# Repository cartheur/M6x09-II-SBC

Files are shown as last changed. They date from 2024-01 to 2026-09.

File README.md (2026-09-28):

## M6x09-II-SBC

A minature seventeen-component singleboard computer to experiment with the `x09` architecture. The sister repository can be found [here](https://github.com/cartheur/M6x09-A).

The Linux terminal application for connecting to this board via FTDI is documented [here](terminal/README.md).

### Working Readmes

For the active Linux-side workflow, start here:

- [Linux terminal bring-up](terminal/README.md)
- [ROM build and Batronix Barlino II 32P burn flow](roms/README.md)
- [ASSIST09 source tree](src/README.md)

The current ROM monitor source is [ASSIST09 source](src/assist-09/assist09.asm).

_Preface_

So often, engineers go crazy on adding features to create the perfect singleboard computer. In the 8-bit world, it is really most interesting to get to the nut of the matter: Can we create the simplest hardware system to test those things we are building-out, such as the bits of a novel kernel or memory management, or evolution to multiprocessing?

This project is what we can discern is the _minimal_ system using modern connetions to a laptop running debian where we can get to understanding how the _ideal_ is in terms of _novel metal_.

_Insistences_

The ideal project should NOT be exploited into higher monetary platitudes simply because people love it. Rather, what open-source tools are the most trustworthy (free of manipulation by intellectual corruption) that will have any engineer who replicates this project have the same success in whatever the future time may be?

_The board_

Layout (v1.1)

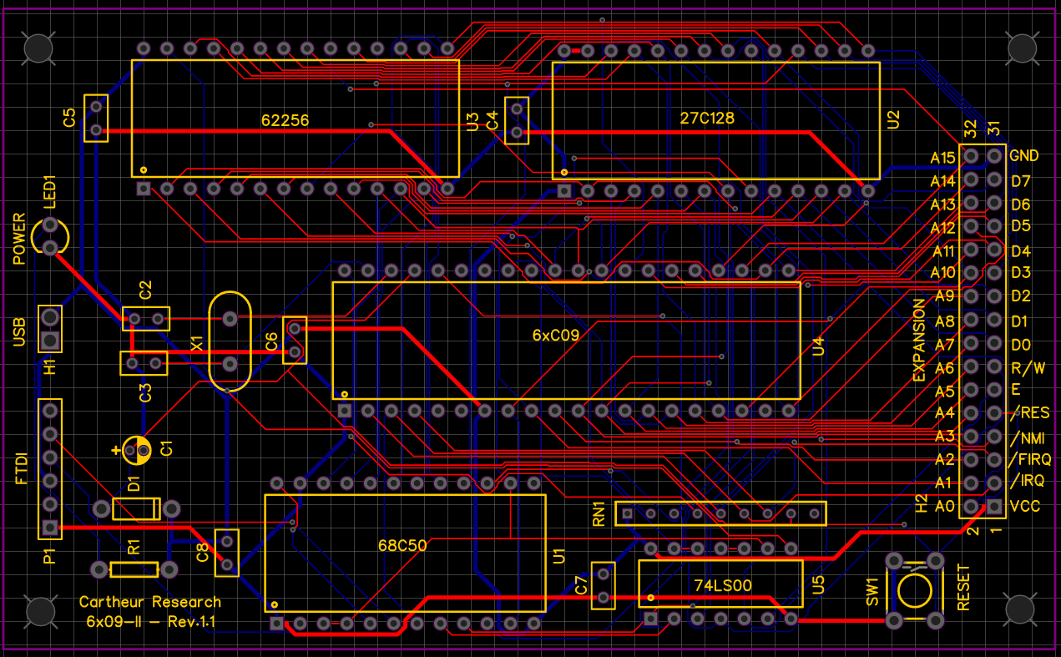
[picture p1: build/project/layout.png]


The manufactured ouput (unassembled version).

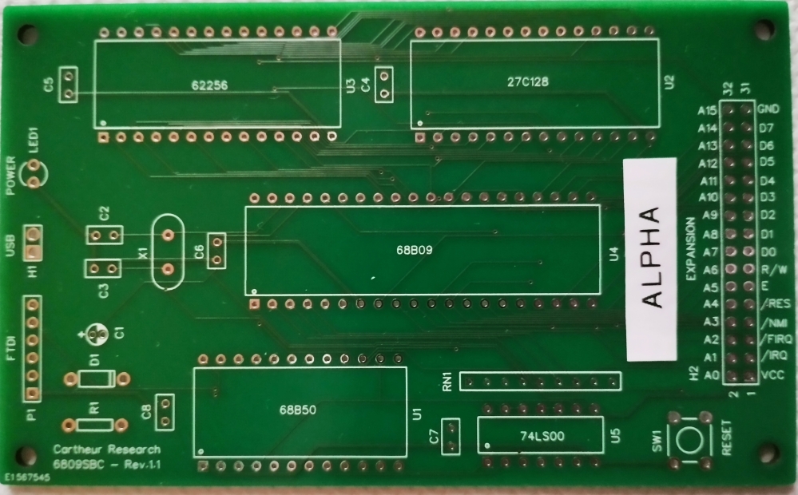
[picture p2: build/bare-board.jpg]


_Parts list_

| ID | Name | Designator | Footprint | Quantity | Part Number | Manufacturer | Supplier | Supplier Part Number | Unit Price (EUR) |
| --- | --- | --- | --- | --- | --- | --- | --- | --- | --- |
| 1 | 10uF | C1 | CAP-D3.0XF1.5 | 1 | ECA-1VM100 | Panasonic | Mouser | 667-ECA-1VM100 | 0.167 |
| 2 | 18pF | C2-C3 | RAD-0.1 | 2 | K180J15C0GF5TL2 | Vishay | Mouser | 594-K180J15C0GF5TL2 | 0.214 |
| 3 | 0.1uF | C4-C5-C6-C7-C8 | RAD-0.1 | 5 | K104K15X7RH53H5G | Vishay | Mouser | 594-K104K15X7RH53H5G | 0.698 |
| 4 | 1N914 | D1 | DO-35 | 1 | 1N914 | Fairchild | Mouser | 512-1N914 | 0.093 |
| 5 | USB POWER JUMPER | H1 | HDR-2X1/2.54 | 1 | 826629-2 | TE Connectivity | Mouser | 571-826629-2 | 0.316 |
| 6 | EXPANSION HEADER | H2 | HDR-16X2/2.54 | 1 | 5-146257-8 | TE Connectivity | Mouser | 571-5-146257-8 | 2.25 |
| 7 | POWER | LED1 | LED-3MM/2.54 | 1 | HLMP-1503 | Broadcom | Mouser | 630-HLMP-1503 | 0.428 |
| 8 | USB FTDI | P1 | HDR-6X1/2.54 | 1 | 5-146281-6 | TE Connectivity | Mouser | 571-1032396 | 0.693 |
| 9 | 330 | R1 | AXIAL-0.3 | 1 | RN60D3300FB14 | Vishay | Mouser | 71-RN60D3300F | 0.285 |
| 10 | 2.2K | RN1 | SIP-9 | 1 | 4609X-101-222LF | Bourns | Mouser | 652-4609X-1LF-2.2K | 0.428 |
| 11 | RESET | SW1 | TACTILE-PTH-EZ | 1 | TS02-66-50-BK-100-LCR-D | CUI Devices | Mouser | 179-TS026650BK100LCR | 0.093 |
| 12 | 68B50 | U1 | DIP24-600 | 1 | DILB24P-223TLF | Amphenol | Mouser | 649-DILB24P-223TLF | 0.503 |
| 13 | 27C128 | U2 | DIP28-600 | 1 | 1-2199299-2 | TE Connectivity | Mouser | 571-1-2199299-2 | 0.688 |
| 14 | 62256P | U3 | DIP28-600 | 1 | 1-2199299-2 | TE Connectivity | Mouser | 571-1-2199299-2 | 0.688 |
| 15 | 6xC09 | U4 | DIP40-600-Ladder | 1 | 1-2199299-5 | TE Connectivity | Mouser | 571-1-2199299-5 | 0.874 |
| 16 | 7.3728 MHz | X1 | OSC-49S-1 | 1 | ABL-7.3728MHZ-B2 | Abracon | Mouser | 815-ABL-7.3728-B2 | 0.307 |
| 17 | 74LS00 | U5 | DIP14-300 | 1 | 1-2199298-3 | TE Connectivity | Mouser | 571-1-2199298-3 | 0.205 |

### Project notes

05.01.2024: Board _alpha_ has been assembled awaiting inserting chips.

08.01.2024: Board _gamma_ has been assembled awaiting inserting chips.

13.01.2024: Dream confirms this is the project to be focusing all attention upon.

15.01.2024: Beginning the final assembly of _alpha_, then will continue to the assembly of _gamma_. Printed labels affixed to each.

26.09.2026: Actively debugging the board. A few stupid errors found so creatig an emulator to check the worst-cases before burning ROM.

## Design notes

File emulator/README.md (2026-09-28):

# M6x09-II-SBC Emulator

This directory contains the first C-based host model for the M6x09-II-SBC. Its purpose is to establish firmware behaviour independently of the physical board; it does not replace electrical bring-up.

## Scope

The current model provides:

- a deliberately partial MC6809 execution core behind a small adapter interface;
- 32 KiB RAM at `$0000-$7FFF`;
- an unmapped region at `$8000-$9FFF`;
- a minimal 6850-compatible ACIA with control/status at `$BE00` and data at `$BE01`;
- a 16 KiB ROM at `$C000-$FFFF` loaded from `roms/assist09-27c128.bin`;
- traceable reads of `$FFFE-$FFFF` and reset-vector loading into the CPU program counter.

The current implementation provides the memory map, ROM loader, ACIA state model, reset-vector trace, and a deliberately small 6809 instruction subset. That subset executes ASSIST09's vector-initialization routine through its return to `$F83D`, plus its ACIA setup and transmit-polling routines. The 6850 model follows the schematic's direct `A0 -> RS` connection and the 6850 register-select definition: `$BE00` is control/status and `$BE01` is data. Unsupported instructions stop explicitly. It is not yet a complete 6809 implementation.

The emulator makes ACIA status flags controllable by tests. The regression suite protects the corrected ASSIST09 contract: receive tests `RDRF` (bit 0), while transmit tests `TDRE` (bit 1).

It will not validate EPROM programming or orientation, power rails, reset circuitry, clocks, FTDI voltage levels, or PCB wiring. Those remain board-debugging work.

## Layout

```text
emulator/
├── Makefile
├── README.md
├── src/                 # host-side C implementation
├── tests/               # native C regression tests
└── build/               # ignored executables, traces, and generated fixtures
```

Generated files must stay in `build/`; only source, tests, documentation, and deliberately preserved reference traces belong in git.

## Build Contract

The emulator is a native host program and should build with a C compiler:

```bash
make -C emulator
```

Firmware is assembled separately, then loaded by the emulator:

```bash
make -C src/assist-09 programmer-image
make -C emulator run ROM=../roms/assist09-27c128.bin
```

Run the native regression tests with:

```bash
make -C emulator test
```

The repository's checked-in `src/assembler/as9` executable is a legacy 32-bit binary and does not run on the current host. `make -C src/assembler as9-host` rebuilds an ignored native replacement with GNU89-compatible compiler mode; the ASSIST09 and Forth Makefiles use that replacement.

## First Milestones

1. Load the preserved 16 KiB ASSIST09 programmer image and assert its size. **Done.**
2. Reset the CPU and assert reads from `$FFFE-$FFFF` resolve to `$F837`. **Done.**
3. Execute the corrected ACIA setup and transmit-polling routines. **Done.**
4. Extend the 6809 core from the reset-vector and ACIA-routine subsets into the SWI monitor path.
5. Extend the minimal ACIA model to capture monitor output over a sequence of transmitted bytes.
6. Assemble and execute the RAM smoke-test fixture at `$1000`.
7. Preserve a concise reset/console trace to compare against the physical board session.

## Podcast Value

The emulator provides a repeatable evidence trail: it can show the reset vector, firmware decision points, ACIA register state, and expected output byte by byte. The scope and terminal captures from the actual SBC can then confirm where physical behaviour diverges from that model.

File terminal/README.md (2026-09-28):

# M6x09 Linux Terminal Bring-Up

This folder contains the Linux-side terminal workflow for the M6x09-II SBC. The intent is to keep a stable monitor in ROM and do normal development over serial by loading code into RAM.

## What This Uses

- [m6x09-terminal.tcl](m6x09-terminal.tcl) as the host terminal
- `H1` as the optional USB-power jumper between `P1_3` and board `VCC`
- ASSIST09 in ROM for prompt, inspection, S-record load, and RAM execution

## Recommended Host Setup

Install Tcl/Tk if needed:

```bash
sudo apt-get install tk
```

Launch the terminal:

```bash
wish terminal/m6x09-terminal.tcl -device /dev/ttyUSB0 -baud 115200
```

Recommended settings in the terminal window:

- Device: `/dev/ttyUSB0` or `/dev/serial/by-id/...`
- Speed: `115200`
- ParityAndBits: `n,8,1`
- Hand Shake: `none`
- Pause(ms): `2`

The script is tuned for prompt-driven, line-paced uploads. It waits for a carriage return before sending the next line, which matches the repo note that uploads need pacing because there is no hardware handshaking.

`115200` is the expected initial rate for the corrected ASSIST09 candidate: the schematic connects the 6850's receive and transmit clocks to the 6809 `E` clock, and the candidate selects the ACIA divide-by-16 mode with control byte `$51`. With the board's 7.3728 MHz oscillator, that implies 115200 baud. The earlier 19200 setting applies only to the pre-correction bring-up attempt and is retained as historical evidence.

## P1 Wiring

`P1` is a 1x6 FTDI-style header with the following board connections:

- `P1` pin 1 = `GND`
- `P1` pin 3 = `P1_3`
- `P1` pin 4 = `U1_2`
- `P1` pin 5 = `U1_6`

The ACIA package `U1` is a 68B50/6850-compatible part whose serial pins are:

- pin 2 = `Rx Data`
- pin 6 = `Tx Data`

That makes the practical hookup:

- FTDI `GND` -> `P1` pin 1 `GND`
- FTDI `TXO` -> `P1` pin 4 `U1_2` -> ACIA `Rx Data`
- FTDI `RXI` -> `P1` pin 5 `U1_6` -> ACIA `Tx Data`
- FTDI `VCC` -> `P1` pin 3 only if you intentionally want the FTDI board to power the SBC
- FTDI `DTR` not required for console use

## Power Notes

`P1_3` is not just a logic pin. It is tied to `H1`, the `USB POWER JUMPER`, which bridges that node to board `VCC`.

Use one power strategy at a time:

- If powering the board from the FTDI breakout, fit `H1` and connect FTDI `VCC` to `P1` pin 3.
- If powering the board some other way, leave FTDI `VCC` disconnected unless you have verified the power path.

Do not back-power the board from two sources at once.

## First Bring-Up

1. Connect `GND`, `TXO`, and `RXI`.
2. Apply power.
3. Start the terminal.
4. Press Enter a few times or use `M6x09 -> Send CR`.
5. Confirm that you get an `ASSIST09` banner and `>` prompt.

Useful first commands:

```text
R
D 1000 20
```

Expected behavior:

- `R` shows registers
- `D` displays memory

Use the acceptance sequence in [roms/README.md](../roms/README.md) to load `assist09-smoke.s19` at `$1000` and prove serial loading and RAM execution. `G D000` is only relevant after a separately validated combined BASIC ROM is installed.

## Programming Strategy

Use the ROM as infrastructure, not as your inner-loop target.

The recommended loop is:

1. Keep ASSIST09 in EPROM as the bootstrap and debugger.
2. Assemble code on Linux.
3. Send Motorola S-records over serial into RAM.
4. Run and debug from RAM.
5. Burn a new EPROM image with the Batronix Barlino II 32P only when a RAM build is stable enough to preserve.

For the ASSIST09 build and ROM acceptance sequence, see [roms/README.md](../roms/README.md).

## Sending Files

Use `File -> Send...` in the Tcl terminal to send text or S-record files line by line. The script's send path is intentionally conservative:

- characters are sent one at a time
- a CR is appended at end of line
- the next line waits for a CR response

If uploads stall:

- keep `Hand Shake` on `none`
- increase `Pause(ms)` from `2` to `5` or `10`
- restart the serial port from the menu
- tap `Send CR` to recover the prompt

## Reference Files In This Repo

- Board overview: [README.md](../README.md)
- Monitor source and build notes: [src/README.md](../src/README.md)
- AS9 source and Makefile: [src/assembler/Makefile](../src/assembler/Makefile)

## External Reference Set

These are the key outside references used to complete the Linux-side picture:

- DFRobot DFR0065 FTDI breakout product page: https://www.dfrobot.com/product-147.html
- DFRobot DFR0065 schematic PDF: https://dfimg.dfrobot.com/enshop/image/data/DFR0065/DFR0065_schematics.pdf
- FT232R product page and datasheet index: https://ftdichip.com/products/ft232rl/
- 6850-compatible pinout reference: https://www.alldatasheet.com/html-pdf/66013/INNOVASIC/IA6850/405/1/IA6850.html

## What To Freeze In ROM

The safest ROM contents for this board are:

- reset vectors
- ASSIST09 monitor
- optional BASIC image
- optional tiny bootstrap helpers

Do not use the EPROM as the place for every experiment. Use it as the stable recovery environment that lets serial development stay fast.

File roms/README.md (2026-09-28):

# ROM Workflow For Batronix Barlino II 32P

This folder is for ROM images that are worth preserving in git and for documenting the build, test, and burn workflow used with the Batronix Barlino II 32P.

The recommended development rhythm is:

1. Build and verify the ASSIST09 ROM baseline on Linux.
2. Program and verify the ASSIST09 EPROM with the Batronix Barlino II 32P.
3. Prove the programmed monitor and serial loader with the ASSIST09 RAM smoke test.
4. Preserve the verified milestone ROM and test record in this folder.

## Source Layout

- Board [memory map](MEMORY-MAP.md)
- Next [Forth port process](NEXT-FORTH-BUILD.md)
- Next-session board [debugging checklist](NEXT-SESSION-DEBUGGING.md)
- ASSIST09 [source](../src/assist-09/assist09.asm)
- Source [notes](../src/README.md)
- AS9 assembler [source](../src/assembler)
- AS9 [build file](../src/assembler/Makefile)

## Build ASSIST09 On Linux

From the repository root, build the assembler and ROM image:

```bash
make -C src/assembler as9
make -C src/assist-09
```

Verify a clean-room rebuild before programming hardware:

```bash
scripts/verify-assist09-image.sh
```

That should produce at least:

- `assist09.lst`
- `assist09.bin`
- `assist09.s19`

The source itself confirms the intended ROM base and ACIA address:

- `ROMBEG EQU $F800`
- `ACIA EQU $BE00`

Those values are in the ASSIST09 [source](../src/assist-09/assist09.asm).

The verifier requires all of the following:

- a 2,048-byte image
- S-record data beginning at `$F800` and ending at `$FFFF`
- reset vector `$F837`
- a byte-for-byte match to the final 2 KiB of the checked-in `roms/assist09-27c128.bin` baseline

fig-Forth is intentionally outside this workflow until its `$E000-$FFFF` ROM and `$C000-$DFFF` RAM assumptions have been adapted to this board.

## Program The ASSIST09 EPROM

The initial ASSIST09 monitor is the exception to the usual "test in RAM first" rule: it must be present in EPROM before it can load the RAM smoke test. Program it only after the host verifier passes.

1. Confirm the marking on the EPROM and select that exact device in the Batronix software. Do not select `27C128` merely because it is the intended part; match the chip actually in the programmer.
2. Read the installed or donor EPROM and save an unmodified backup before erasing or programming it.
3. Build the 16 KiB `27C128` programmer image:

   ```bash
   make -C src/assist-09 programmer-image
   ```

   This creates `roms/assist09-27c128.bin` and `roms/assist09-27c128.bin.sha256`. The board maps ROM at `$C000-$FFFF`, so the file is filled with `0xFF` from `$C000-$F7FF` and places the 2,048-byte ASSIST09 image at EPROM offset `$3800`, corresponding to CPU addresses `$F800-$FFFF`.
4. Load `roms/assist09-27c128.bin` into the Batronix software. Do not load the raw 2 KiB `assist09.bin` as the complete image for a `27C128`.
5. If using a blank or erased replacement, run the Batronix blank check.
6. Program the 16 KiB image, then run the Batronix verify operation.
7. Label the EPROM with `assist09`, the date, image checksum, and device type.
8. Install the EPROM with power removed, check its orientation, then power the board and continue with the terminal acceptance test below.

## Prove The Terminal Workflow

Build the RAM smoke-test S-record:

```bash
make -C src/assist-09 smoke
```

With the newly programmed ASSIST09 EPROM installed and the terminal connected, use this acceptance sequence:

1. Start the terminal as described in [terminal/README.md](../terminal/README.md), reset the board, and record the `ASSIST09` banner and `>` prompt.
2. At the prompt, enter `L` and press Enter.
3. Use `File -> Send...` to transmit `src/assist-09/assist09-smoke.s19`.
4. Wait for the prompt to return without an error, then enter `G 1000`.
5. Record the exact output: `ASSIST09 RAM SMOKE TEST PASSED`, followed by the monitor prompt.

Do not label a ROM image stable until the Batronix verification and this sequence have both been recorded for the specific board, EPROM, serial adapter, and terminal settings used.

## Use RAM As The Fast Loop

Do not reburn EPROM for every test.

Use ASSIST09 as the stable ROM monitor, then:

1. Assemble your program on Linux.
2. Load the S-record through the serial terminal into RAM.
3. Run and debug from RAM.
4. Promote only stable milestones into EPROM.

This keeps the programmer in the outer loop where it belongs.

## What Belongs Here

Commit a ROM image here only when it is a real milestone, for example:

- the first known-good ASSIST09 boot image
- a verified ASSIST09 + BASIC combined image
- an image actually programmed into EPROM with the Batronix Barlino II 32P
- an image tied to a documented hardware or software milestone

## What Does Not Belong Here

Do not commit routine build outputs from `src/assist-09` here.

Normal development artifacts should stay ignored:

- `*.bin`
- `*.lst`
- `*.s19`
- `*.sym`
- `*.crf`

Those files are disposable unless they represent a milestone image.

## Which Build Output Is For Burning

For the current ASSIST09 burn step, build and program the complete 16 KiB device image:

- `roms/assist09-27c128.bin`

Create it with:

```bash
make -C src/assist-09 programmer-image
```

The raw `src/assist-09/assist09.bin` file is only the 2 KiB monitor assembled for CPU addresses `$F800-$FFFF`. It is an input to the programmer-image target, not a complete 27C128 payload. The programmer image fills device offsets `$0000-$37FF` with `0xFF` and places that monitor at offsets `$3800-$3FFF`.

The other build outputs have different roles:

- `*.s19`: useful for serial or RAM loading through ASSIST09
- `*.lst`: listing file for inspection and debug
- `*.sym`: symbol output from the build
- `*.crf`: cross-reference output from the build

For a future ROM layout, preserve and program a complete 16 KiB image whose contents and device offsets are documented alongside it. Do not program a raw partial binary as a full 27C128 image.

## What To Commit With A Milestone ROM

For each preserved ROM, include:

- the ROM image itself
- a checksum file such as `.sha256`
- a short Markdown note describing what it is
- the build date
- the source inputs used to create it
- whether it was tested in RAM before burn
- whether it was programmed into EPROM with the Batronix Barlino II 32P

## Suggested Naming

Use names that carry both purpose and date, for example:

- `assist09-2026-09-04.bin`
- `assist09-basic-combined-2026-09-04.bin`
- `assist09-2026-09-04.bin.sha256`
- `assist09-2026-09-04.md`

## Practical Strategy

Use ASSIST09 as:

- the reset-time recovery environment
- the serial upload target
- the debugger and memory inspector
- the stepping stone to BASIC with `G D000` if that combined ROM is in use

Use the Batronix Barlino II 32P as:

- the preservation tool
- the milestone-publishing tool
- not the inner-loop development tool

## Recommended Workflow

1. Build in `src/assist-09`.
2. Test over serial in RAM, typically using the generated `.s19` file.
3. Build, program, and verify the 16 KiB `assist09-27c128.bin` EPROM image.
4. Run the terminal RAM smoke test against the newly programmed monitor.
5. Copy the final preserved `.bin` ROM image into `roms/`.
6. Add the checksum and short milestone note.

This keeps the main source tree clean while still preserving important ROM history.

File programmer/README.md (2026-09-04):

## Adding the udev rule

Subsequent to installing Batronix 32P ROM burner software via flatpak

* `wget https://www.batronix.com/exe/Batronix/Prog-Express/flatpak/prog-express-3.9.3.flatpak`

The device is not seen on Debian. In order to have it be seen:

* Copy the `udev` rule file, mode `su`
  - `cp /etc/udev/rules.d/85-batronix-devices.rules`
* Reload the rules
  - `sudo udevadm control --reload-rules`
  - `sudo udevadm trigger`
* Test the rule
  - `udevadm test /sys/class/tty/ttyUSB0`

The device will now be seen by the software.

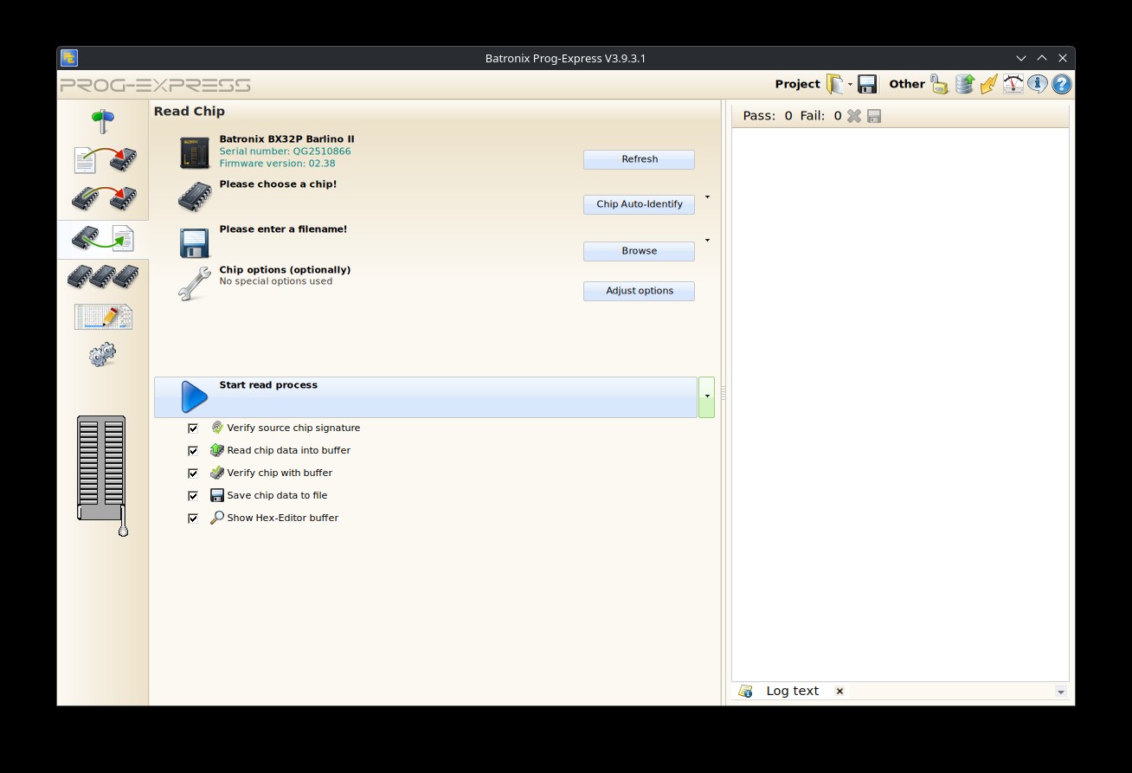
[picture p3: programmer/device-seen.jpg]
seen


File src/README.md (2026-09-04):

## M6809 Monitor And Language Sources

This folder contains the checked-in 6809 source tree used as the software starting point for the M6x09-II SBC.

## Contents

- [assist09.asm](assist-09/assist09.asm)
  - Motorola ASSIST09 monitor, adapted for the 6850 ACIA on this board
- [forth09.asm](forth-09/forth09.asm)
  - 6809 fig-Forth source
- [ASSIST09 Makefile](assist-09/Makefile)
  - the validated ROM baseline and RAM smoke-test build targets
- [Forth Makefile](forth-09/Makefile)
  - a separate, provisional Forth build

## Why ASSIST09 Matters Here

ASSIST09 is the best ROM starting point for this machine.

It gives the board:

- a reliable serial monitor at reset
- memory display and modification
- register display and modification
- breakpoints and program control
- Motorola S-record `LOAD` and `PUNCH` support

That makes it ideal as the ROM-resident bootstrap while normal development happens by loading code into RAM over serial.

## Board-Specific Notes

This copy of ASSIST09 was adapted to use the board's 6850 ACIA. In the source:

- `ROMBEG EQU $F800`
- `ACIA EQU $BE00`

Those values are defined directly in [assist09.asm](assist-09/assist09.asm).

## Build

Build the assembler first:

```bash
make -C src/assembler as9
```

Then build and verify ASSIST09:

```bash
make -C src/assist-09
scripts/verify-assist09-image.sh
```

Build the terminal smoke-test S-record with:

```bash
make -C src/assist-09 smoke
```

Expected ASSIST09 artifacts:

- `assist09.bin`
- `assist09.lst`
- `assist09.s19`

Forth is not part of the ROM baseline: it currently assumes a different `$E000-$FFFF` ROM and `$C000-$DFFF` RAM map. Build it only for separate investigation:

```bash
make -C src/forth-09
```

## Development Workflow

The intended workflow for this repo is:

1. Keep ASSIST09 in ROM.
2. Bring the board up over the FTDI-style serial header.
3. Assemble code on Linux.
4. Load S-records into RAM over serial.
5. Burn EPROM with the Batronix Barlino II 32P only when the image is stable.

That keeps ROM as the recovery layer and RAM as the fast iteration layer.

## BASIC Context

The broader project notes describe a combined ASSIST09 + BASIC ROM arrangement where BASIC is reached with:

```text
G D000
```

That is still a useful target layout, but ASSIST09 should remain the canonical first-stage monitor because it gives the cleanest bring-up and debug path.

## Historical Notes

These sources were carried forward from earlier salvage work around a simple 6809 SBC software stack:

- Microsoft Extended BASIC, reduced for serial-only use
- ASSIST09 for monitor and debug work
- fig-Forth as another language/runtime candidate

The older background writeup was valuable historically, but the practical working guidance now lives in:

- [terminal/README.md](../terminal/README.md)
- [roms/README.md](../roms/README.md)

## References

- AS9 assembler notes: [as9.md](as9.md)
- AS9 source: [src/assembler](assembler/)
- Earlier project background: http://land-boards.com/blwiki/index.php?title=RetroComputers
- Related salvage repo: https://github.com/cartheur/SalvagedRetro/tree/master/6809

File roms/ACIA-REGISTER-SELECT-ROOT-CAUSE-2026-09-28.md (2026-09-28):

# ACIA Register-Select Root Cause

Date: 2026-09-28

Status: source repair implemented, programmed, and full-device-readback verified. Post-repair measurement shows active `RS` but idle `TXDATA`; board boot and serial acceptance remain pending while CTS is investigated.

## Issue

The previously programmed ASSIST09 EPROM was read back successfully and matched its intended 16 KiB image byte for byte, but the Alpha board produced no intelligible serial monitor output. A Gamma-board cross-check was also silent. The ROM contents were therefore reproducible, but not functionally correct for the hardware ACIA mapping.

## Hardware Evidence

The debugging session established the prerequisites before changing source:

- FTDI-powered supply was corrected to about 4.56 V.
- `/RESET` was measured at H2 pin 7. It rises through the board's RC network and settles near 4.5 V after approximately 100–150 ms.
- CPU `E` clock at H2 pin 9 measured 1.8431 MHz.
- Lower address lines A0–A11 showed continuing bus activity after reset release.
- U1 pin 4 (`TXCLK`) measured 1.8427 MHz and U1 pin 3 (`RXCLK`) measured 1.8445 MHz.
- U1 pin 6 (`TXDATA`) showed short digital transmit bursts instead of remaining idle.
- U1 pin 11 (`RS`) was active during CPU accesses.

The clock and TX evidence ruled out a dead CPU, absent ACIA clocks, or a purely terminal-side failure. The short TX bursts were inconsistent with the expected 115200-baud character timing.

## Root Cause

The MC6850/68C50 register-select definition is:

| U1 `RS` level | Register pair |
| --- | --- |
| 0 | Control (write) / Status (read) |
| 1 | Transmit Data (write) / Receive Data (read) |

The board schematic connects CPU A0 directly to U1 pin 11 (`RS`). Consequently:

| CPU address | A0 / `RS` | ACIA function |
| --- | --- | --- |
| `$BE00` | 0 | Control/Status |
| `$BE01` | 1 | Data |

The previous monitor source had those offsets reversed. It wrote the intended master-reset byte `$03` and configuration byte `$51` to `$BE01`, which is the transmit-data register, not the control register. The ACIA consequently remained in its default divide-by-1 state and transmitted those initialization bytes as short raw data bursts. The same reversal made transmit polling read the data register rather than status, and made normal output writes target control rather than transmit data.

This explains all of the otherwise conflicting observations: a valid readback, a live CPU and ACIA clock, visible TX transitions, and no usable `115200,n,8,1` console output.

## Error History And Provenance

This was not a single-source error.

1. Commit `09b68ca` (`Arrange`, 2026-08-18) brought the archived ASSIST09 source into its then-current repository location. Its `CIDTA` and `CODTAO` paths already treated offset 1 as status/control and offset 0 as data, the inverse of the 6850 pinout. Its initialization stores were still at offset 0.
2. Commit `da931d913b926a7f5ef3978d7367b10e5c7b68cf` (`Fix ASSIST09 ACIA initialization and polling`, 2026-09-28) changed the initialization stores from offset 0 to offset 1 while attempting to correct ACIA behavior. Per the project owner, this commit was made by an agent operating under the `cartheur` account. It extended the inherited register-map error to the `$03` reset and `$51` configuration writes, making the ACIA configuration failure complete.
3. Commit `0b656cd` (`Document ACIA register-select diagnosis`, 2026-09-28) records the hardware evidence that surfaced the combined error: valid ROM readback, correct reset and clocks, live ACIA TX, correct ACIA clocks, and active `RS`.

Git metadata alone identifies the account (`cartheur`) but does not distinguish a human from an agent. The agent attribution for `da931d9` is recorded here on the project owner's confirmation.

This history is also a podcast lesson: an agent can make an honest, plausible mistake, especially where a simulator and a hardware data sheet disagree. The developer remains responsible for checking the actual pinout, reviewing changes, and accepting the diagnosis only when source, instruments, and hardware evidence agree.

## Implemented Repair

The register offsets in `src/assist-09/assist09.asm` are now corrected in all three ACIA paths:

| Routine | Previous behavior | Correct behavior |
| --- | --- | --- |
| `CIDTA` | Status at offset 1; received data at offset 0 | Status at offset 0; received data at offset 1 |
| `COON` | `$03` and `$51` written at offset 1 | `$03` and `$51` written at offset 0 |
| `CODTAO` | Poll offset 1; transmit at offset 0 | Poll offset 0; transmit at offset 1 |

The emulator's 6850 model, regression test, and explanatory README were corrected to use the same hardware map.

## New Candidate Image

| Artifact | SHA-256 |
| --- | --- |
| New raw 2 KiB monitor | `3904c6277ab60bc03528475e4522bc5c8da37a09458d56687634842894f9c12c` |
| New 16 KiB programmer image | `37ece487da6b49c7d9f24deb34d25598983782a9ff958558f39a1dff2e5cc843` |
| Previous programmed EPROM readback | `1d7fdbe412c8e57084b99b981a24c8fbdbc013227a6da04b1810c67054aa2d72` |

The new programmer image differs from the old verified readback in six bytes, as expected for this source repair.

## Host Verification

The repaired candidate passes:

```bash
make -C emulator test
scripts/verify-assist09-image.sh
(cd roms && sha256sum -c assist09-27c128.bin.sha256)
```

## Programming And Readback Result

At 19:03 on 2026-09-28, the repaired candidate was programmed and a complete 16,384-byte device readback was saved as `roms/readback.bin`. Its SHA-256 is `37ece487da6b49c7d9f24deb34d25598983782a9ff958558f39a1dff2e5cc843`, identical byte for byte to `roms/assist09-27c128.bin`. This verifies the burn; it does not yet verify execution on the board.

## Post-Repair Scope Result

With the corrected EPROM installed, Tcl still received no banner or prompt at `115200,n,8,1`, no handshake. The following checks preserve the distinction between an electrical observation and a source conclusion:

- Power-off continuity confirms H2 pin 2 (`A0`) to U1 pin 11 (`RS`); U1 pin 11 has no continuity to adjacent U1 pin 12 (`VCC`).
- `same-acia.jpg` puts both AD2 scope channels on U1 pin 11 with a shared ground. Both channels show the same active `RS` signal, resolving an earlier probe/ground-contact mismatch.
- `split-acia.jpg` uses C1 on U1 pin 11 (`RS`) and C2 on U1 pin 6 (`TXDATA`) at 100 us/div after reset. `RS` is active, while `TXDATA` remains idle high.

The ACIA is therefore being addressed, but transmission is not becoming ready. The immediate next hypothesis is U1 pin 23 (`CTS`): the MC6850 data sheet states that high CTS inhibits `TDRE`, exactly the status bit the monitor polls before writing TX data. No further source change is justified until CTS is measured.

## Next Hardware Step

Measure U1 pin 23 (`CTS`) relative to board ground. It must be low (near 0 V) for `TDRE` to assert; a level near the 4.5 V supply would explain the idle TX line. Optionally observe U1 pin 5 (`RTS`) at the same time. Keep the corrected ROM installed and make no source change before recording that result.

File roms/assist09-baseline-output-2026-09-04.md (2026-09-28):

# ASSIST09 Baseline Output Record

Date: 2026-09-04

Status: the ACIA register-map-corrected candidate has passed full-device readback; board boot and serial acceptance pending.

This record began as the first output of the M6x09-II-SBC ROM workflow. The original baseline exposed an ACIA register-selection and status-polling defect in the emulator, so the current preserved image is an ACIA-corrected candidate rather than the original untested baseline.

The original raw 2 KiB monitor SHA-256 was `15d015d50df6a71fae61c459c2d009f251f08c9bb8c7a3dbd0bf1524cac1d394`. It remains historical evidence only; do not program it for the next board session.

## Inputs

- Monitor [source](../src/assist-09/assist09.asm)
- AS9 [assembler](../src/assembler)
- Image [verifier](../scripts/verify-assist09-image.sh)
- Terminal [smoke test](../src/assist-09/assist09-smoke.asm)

## Host Verification Result

The clean-room AS9 rebuild completed successfully and matched the final 2 KiB of the checked-in `roms/assist09-27c128.bin` programmer image byte for byte after the ACIA register-map repair.

| Check | Result |
| --- | --- |
| Binary size | 2,048 bytes |
| ROM address range | `$F800-$FFFF` |
| Final S-record address | `$FFF0` |
| Reset vector | `$F837` |
| Register-map-corrected 2 KiB monitor SHA-256 | `3904c6277ab60bc03528475e4522bc5c8da37a09458d56687634842894f9c12c` |
| Register-map-corrected 16 KiB programmer image SHA-256 | `37ece487da6b49c7d9f24deb34d25598983782a9ff958558f39a1dff2e5cc843` |

Run the same check from the repository root with:

```bash
scripts/verify-assist09-image.sh
```

## Hardware Acceptance Gate

The corrected candidate was programmed and passed the complete programmer-readback check below, but board boot and serial acceptance remain pending.

## Earlier Programmer Readback Record

Date: 2026-09-28

The earlier 16 KiB candidate was programmed using the Windows host. A full-device readback was saved as [readback.bin](readback.bin) and compared byte for byte with the then-current programmer image on Linux. That image has since been superseded by the ACIA register-map repair below.

| Check | Result |
| --- | --- |
| Readback size | 16,384 bytes |
| Comparison with then-current programmer image | Identical (byte for byte) |
| Readback SHA-256 | `1d7fdbe412c8e57084b99b981a24c8fbdbc013227a6da04b1810c67054aa2d72` |
| Current register-map-corrected image checksum | `37ece487da6b49c7d9f24deb34d25598983782a9ff958558f39a1dff2e5cc843` (does not match; expected) |

`readback.txt` was renamed to `readback.bin`; it is raw binary data, not a text log. That filename now holds the later corrected-candidate readback recorded below; the values in this section are retained as historical evidence of the earlier burn.

## Corrected-Candidate Programmer Readback

Date/time: 2026-09-28 19:03

The corrected 16 KiB image was programmed and read back in full as [readback.bin](readback.bin). It matches the current `assist09-27c128.bin` byte for byte.

| Check | Result |
| --- | --- |
| Readback size | 16,384 bytes |
| Readback SHA-256 | `37ece487da6b49c7d9f24deb34d25598983782a9ff958558f39a1dff2e5cc843` |
| Comparison with current programmer image | Identical (byte for byte) |

## First Boot Attempt

Date: 2026-09-28

With the EPROM image verified by full-device readback, the board was reset with the terminal configured for `115200,n,8,1`, no handshake. No `ASSIST09` banner or `>` prompt was received. A separate direct 45-second FTDI capture, including a transmitted carriage return and a board reset during the capture, received zero bytes. This rules out the Tcl terminal display as the immediate cause. Hardware acceptance therefore remains pending.

## Reset And CPU-Timing Milestone

Date: 2026-09-28

The reset and CPU prerequisites for serial output have now been demonstrated with a Digilent Analog Discovery 2 (AD2). They do not yet establish ACIA output or a successful monitor boot.

| Check | Observation | Result |
| --- | --- | --- |
| Supply after FTDI jumper correction | About 4.56 V at the FTDI-powered board | Present, but with little 5 V margin |
| `/RESET` release | AD2 Scope on H2 pin 7 (`/RESET`) shows a low level while the button is held, then a smooth RC rise to about 4.5 V over roughly 100–150 ms | Passed |
| CPU `E` clock | 1.8431 MHz measured at H2 pin 9 (`E`) | Passed; matches the 7.3728 MHz oscillator / divide-by-four design |
| Lower address bus | AD2 Logic Analyzer capture on H2 pins A0–A11 shows repeated changing values while reset is released | CPU bus is active |

The reset release is intentionally slow because of the board's reset RC network. The short 40.96 us logic-analyzer capture initially appeared to show reset chatter; the longer scope capture ([ch2-trigger-02.jpg](../images/ch2-trigger-02.jpg)) shows that this was the analyzer sampling the slow analog threshold crossing, not a reset oscillation. Consequently, a reset-vector fetch cannot be inferred from the short capture alone.

### AD2 Diagnostic Procedure Used

1. Connect AD2 ground to board ground.
2. Scope H2 pin 7 (`/RESET`) with the AD2 differential scope input (`2+` to `/RESET`, `2-` to ground); use a long timebase to capture both pressing and releasing reset.
3. Confirm the released reset level reaches approximately 4.5 V and remains there.
4. Scope H2 pin 9 (`E`) and confirm approximately 1.8432 MHz.
5. Connect AD2 digital inputs to H2 A0–A11, group them as a hexadecimal `A[11:0]` bus, and confirm ongoing address activity after reset is released.
6. Do not treat an AD2 digital rising-edge trigger as a clean reset-release event while the RC ramp is crossing its input threshold.

Next diagnostic: probe ACIA TX at U1 pin 6 / P1 pin 5 with the AD2 Scope after the reset-release delay. It should idle high and show 115200-baud activity while ASSIST09 emits its banner. If it remains idle, investigate the ACIA supply, chip select/control signals, and the U1-to-P1 TX path before revisiting terminal software.

## ACIA Register-Select Diagnosis

Date: 2026-09-28

The ACIA transmit investigation reached a source-level conclusion. AD2 captures establish that the physical prerequisites are present:

- U1 pin 4 (`TXCLK`) measures 1.8427 MHz.
- U1 pin 3 (`RXCLK`) measures 1.8445 MHz.
- U1 pin 11 (`RS`) is active during CPU bus accesses.
- U1 pin 6 (`TXDATA`) idles high near 4.7 V and produces short digital transmit bursts.

The bursts are far shorter than an 115200-baud character. The local [MC6850 data sheet](../build/datasheets/MC6850.pdf) defines `RS=0` as Control/Status and `RS=1` as Transmit/Receive Data. The board schematic connects CPU A0 directly to U1 pin 11 (`RS`), so `$BE00` selects Control/Status and `$BE01` selects Data.

The previous monitor source used those offsets in reverse: it wrote the intended ACIA reset (`$03`) and configuration (`$51`) to offset 1, and read status/wrote transmit data at offset 0. The observed short TX bursts are consistent with `$03` and `$51` being emitted as data while the ACIA remained in its default divide-by-1 mode.

The next source change swaps those register offsets in `CIDTA`, `COON`, and `CODTAO`:

| Operation | Current offset | Required offset |
| --- | --- | --- |
| Read status | 1 | 0 |
| Read received data | 0 | 1 |
| Write control (`$03`, `$51`) | 1 | 0 |
| Read transmit status | 1 | 0 |
| Write transmit data | 0 | 1 |

The source repair has now been applied, including the matching emulator model and regression tests. It preserves the 2,048-byte monitor size. The new 16 KiB image has SHA-256 `37ece487da6b49c7d9f24deb34d25598983782a9ff958558f39a1dff2e5cc843`; it passes `make -C emulator test`, `scripts/verify-assist09-image.sh`, and its checksum check. It differed in six bytes from the earlier readback, as expected, and the corrected candidate's full readback now matches it exactly.

Complete and record these remaining observations on the target board:

1. With power removed, install the EPROM, confirming its orientation and exact device type.
2. Start the terminal at `115200`, `n,8,1`, with no handshake; reset the M6x09-II-SBC and record the ASSIST09 banner and `>` prompt.
3. Build the RAM test with `make -C src/assist-09 smoke`.
4. At the monitor prompt, enter `L`, send `src/assist-09/assist09-smoke.s19`, then enter `G 1000`.
5. Record `ASSIST09 RAM SMOKE TEST PASSED` followed by the monitor prompt.

Only after those observations are recorded should a copied ROM image, checksum file, and completed milestone note be committed under `roms/`.

## Post-Repair ACIA State

The corrected EPROM has now been programmed and verified by complete readback, but the terminal still receives no banner or prompt. A misleading initial scope comparison was resolved by a shared-ground, same-pin check: both AD2 channels on U1 pin 11 (`RS`) show the same active waveform ([same-acia.jpg](../images/same-acia.jpg)). Power-off continuity also confirms H2 pin 2 (`A0`) to U1 pin 11, with no continuity from U1 pin 11 to VCC on U1 pin 12.

The subsequent split capture ([split-acia.jpg](../images/split-acia.jpg)) places C1 on U1 pin 11 (`RS`) and C2 on U1 pin 6 (`TXDATA`). After reset, `RS` is active but `TXDATA` remains idle high. The next session must measure U1 pin 23 (`CTS`) relative to ground: high CTS inhibits the ACIA `TDRE` bit and would make the monitor's transmit polling loop wait indefinitely. Do not change source until that measurement is recorded.

## Episode 10 Shadow

This technical record is paired with the Episode 10 companion note in `The Last Cyberneticist`. The pairing makes the episode's claim concrete: reproducibility is demonstrated by a build, an image check, a serial RAM test, and a preserved hardware result.

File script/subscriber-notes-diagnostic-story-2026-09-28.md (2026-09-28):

# Subscriber Notes: The Board That Was Silent

Date: 2026-09-28

## The Short Version

The new ASSIST09 EPROM image was not the cause of the silence. A full 16 KiB readback from the Windows programmer matched the Linux-built image byte for byte. Yet neither the Alpha board nor the Gamma cross-board check produced a serial character.

The investigation then moved outward from the ROM: serial host, supply, reset, clock, CPU bus, and finally the ACIA transmit path. The useful lesson is not that every first measurement was right; it is that each measurement narrowed the next question.

## Storyboard

### 1. The ROM Was Real

The programmer readback, preserved as `roms/readback.bin`, is identical to `roms/assist09-27c128.bin`. The image is 16,384 bytes and has SHA-256 `1d7fdbe412c8e57084b99b981a24c8fbdbc013227a6da04b1810c67054aa2d72`. The binary file is the evidence; it merely looked corrupt when it was initially opened as text.

### 2. Silence Was Not a Terminal Rendering Problem

The FTDI device was visible as `/dev/ttyUSB0`, and the Tcl terminal opened it at `115200,n,8,1`, no handshake. A direct 45-second capture, including a transmitted carriage return and a board reset, received zero bytes. The absence of an `ASSIST09` prompt was therefore physical evidence, not a GUI display issue.

### 3. The Analyzer Found Life on the Bus

The first Logic Analyzer views turned individual lines into an address-bus question. Once A0–A11 were grouped as a hexadecimal bus, the capture showed repeated changing values rather than a frozen machine.

Suggested figures:

- [logic-analyzer.jpg](../images/logic-analyzer.jpg) — the initial raw bus activity.
- [logic-analyzer-run.jpg](../images/logic-analyzer-run.jpg) — a running capture.
- [busses.jpg](../images/busses.jpg) — the decisive `A[11:0]` bus grouping.

Technical appendix:

- [logic-export.csv](../images/logic-export.csv) — raw 100 MHz bus capture.

### 4. Reset Looked Broken Until the Measurement Was Questioned

The short digital capture made `/RESET` appear to chatter. This was a productive false lead: it showed that a 40.96 us digital window cannot describe a deliberately slow analog reset ramp. The early captures belong in the story as evidence of the method being corrected, not as proof that reset was faulty.

Suggested figures and data:

- [RESET.jpg](../images/RESET.jpg) — the first misleading digital-reset configuration.
- [reset-pressed.jpg](../images/reset-pressed.jpg) and [reset-released.jpg](../images/reset-released.jpg) — early scope attempts, explicitly labelled inconclusive.
- [ch2-trigger.jpg](../images/ch2-trigger.jpg) — the clue: the reset voltage was still only around 2 V in a short view.
- [D015-rise.csv](../images/D015-rise.csv) and [long-reset.csv](../images/long-reset.csv) — raw captures that explain the misleading threshold transitions.

### 5. The Long Scope Capture Resolved Reset

The AD2 scope, connected to H2 pin 7 (`/RESET`) with its negative input at board ground, was given a long enough timebase. It showed the expected behavior: Reset stays low while the button is held, then rises smoothly through the RC network and settles near 4.5 V after approximately 100–150 ms.

That changed the conclusion. Reset was not chattering; the logic analyzer had been watching a slow analog signal cross a digital threshold. The corresponding CPU E-clock measured 1.8431 MHz at H2 pin 9, as expected from the 7.3728 MHz oscillator. The installed HD6309 remains compatible with the 6809 assumptions used by ASSIST09.

Primary figure:

- [ch2-trigger-02.jpg](../images/ch2-trigger-02.jpg) — the reset-release resolution; this is the key subscriber image.

### 6. Where the Investigation Stands

The TX probe changed the story again. U1 pin 6 was not silent: it emitted short digital bursts. The receive and transmit clock pins measured approximately 1.843 MHz, so the ACIA clock source was correct. The bursts, however, were far too short to be 115200-baud characters.

The answer was in the relationship between source and pinout. On the 6850, `RS=0` selects Control/Status and `RS=1` selects Data. The board carries CPU A0 directly to U1 pin 11 (`RS`), so `$BE00` is Control/Status and `$BE01` is Data. The monitor source had those offsets reversed. Its two intended initialization bytes, `$03` and `$51`, were being transmitted as raw data while the ACIA remained in its default divide-by-1 mode.

Suggested figures:

- [acia-burst.jpg](../images/acia-burst.jpg) and [acia-burst-narrow.jpg](../images/acia-burst-narrow.jpg) — TX was alive, but its timing was wrong.
- [acia-crystal-01.jpg](../images/acia-crystal-01.jpg) and [acia-crystal-02.jpg](../images/acia-crystal-02.jpg) — both ACIA clocks were correct.
- [RS.jpg](../images/RS.jpg) — register-select activity connecting the bus diagnosis to the firmware mistake.

The next chapter became a deliberately small source repair: Control/Status now uses offset 0; Data now uses offset 1. The matching emulator model was repaired too, and the rebuilt candidate passed its host checks. Its 16 KiB image SHA-256 is `37ece487da6b49c7d9f24deb34d25598983782a9ff958558f39a1dff2e5cc843`. The corrected EPROM was programmed, and its complete 16,384-byte readback matched that image byte for byte. The fresh hardware boot test is now the remaining acceptance step.

That fresh test added one more disciplined stop. A same-pin, shared-ground scope check proved that U1 pin 11 (`RS`) really was active, and continuity proved it follows CPU A0. A split capture then showed active `RS` but idle U1 pin 6 (`TXDATA`). The next question is not another code revision: measure U1 pin 23 (`CTS`). On this ACIA, high CTS prevents transmit-ready from asserting, which would make the monitor wait forever before sending a character.

## The Subscriber Lesson

An agent can make an honest mistake that looks plausible in source code and even passes a model built around the same mistaken assumption. That does not transfer responsibility for diagnosis or acceptance away from the developer. The data sheet, schematic, scope, logic analyzer, readback, and board all remain part of the developer's review loop. Use an agent as a fast collaborator; do not treat it as the final authority on what the hardware is doing.

## Preservation Decision

Delete **none** of the current figures or CSV captures yet. The supposedly unsuccessful captures document the path from an apparent reset failure to the correct RC-reset interpretation. They are useful primary evidence for a subscriber note and a later technical appendix.

For a compact published version, lead with `busses.jpg` and `ch2-trigger-02.jpg`; keep the other JPEGs and all CSV files as linked or downloadable appendix material. A later editorial pass can omit intermediate images from the public page without destroying the underlying record.

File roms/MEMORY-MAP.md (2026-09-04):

# M6x09-II-SBC Memory Map

Use this map when placing ROM code or creating full-device programmer images.

| CPU address range | Size | Assignment |
| --- | ---: | --- |
| `$0000-$7FFF` | 32 KiB | RAM |
| `$8000-$9FFF` | 8 KiB | Unused |
| `$A000-$BFFF` | 8 KiB | Serial interface region |
| `$C000-$FFFF` | 16 KiB | ROM (`27C128`) |

## Current ASSIST09 Placement

| CPU address range | Device offset | Contents |
| --- | ---: | --- |
| `$C000-$F7FF` | `$0000-$37FF` | Available for future ROM code; currently `0xFF` padding |
| `$F800-$FFFF` | `$3800-$3FFF` | ASSIST09 monitor and hardware vectors |

The current ASSIST09 image is 2 KiB and is assembled for `$F800`. The `programmer-image` target creates a complete 16 KiB image for the `27C128`:

```bash
make -C src/assist-09 programmer-image
```

The resulting [assist09-27c128.bin](assist09-27c128.bin) places ASSIST09 at device offset `$3800` so it appears at CPU address `$F800`.

## Rules For Future ROMs

1. Keep the hardware vectors at `$FFF0-$FFFF` unless the ROM design deliberately replaces ASSIST09's reset path.
2. Reserve `$F800-$FFFF` for ASSIST09 when using it as the recovery monitor.
3. Place additional ROM code in `$C000-$F7FF` and document its CPU address range and device offset.
4. Build a full 16 KiB programmer image for the `27C128`; do not program a raw partial binary without placing it at the corresponding device offset.
5. Do not place ROM code in `$0000-$7FFF`, `$8000-$9FFF`, or `$A000-$BFFF`.

The ASSIST09 source uses the serial ACIA at `$BE00`, within the serial-interface region.

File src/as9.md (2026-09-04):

# AS9 Assembler

This repository keeps a salvaged, Linux-portable copy of Motorola's AS9 assembler in [assembler/](assembler/). It is used to build the ASSIST09 monitor and fig-Forth sources without converting their Motorola syntax.

## Build

From the repository root:

```bash
cd src/assembler
make as9
```

The resulting `as9` executable is used by [forth-09/Makefile](forth-09/Makefile) to build ASSIST09 and Forth artifacts.

## Compatibility Notes

- Do not put whitespace inside an operand expression: `bar - foo` is parsed as `bar` followed by a comment.
- The warning option is enabled by default. Use `now` for legacy sources, such as ASSIST09, whose `*` comments otherwise produce warnings.
- `as9n.c` is an alternative entry point for systems without `strncasecmp()`.

## References

- Motorola assembler reference: [as11v2.pdf](../docs/as11v2.pdf)
- Canonical AS9 porting history and caveats: [as9_changes.txt](assembler/as9_changes.txt)

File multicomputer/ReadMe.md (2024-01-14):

## Introduction of Multiprocessor and Multicomputer

_Multiprocessor_

I. A Multiprocessor is a computer system with two or more central processing units (CPUs) share full access to a common RAM. The main objective of using a multiprocessor is to boost the system’s execution speed, with other objectives being fault tolerance and application matching. There are two types of multiprocessors, one is called shared memory multiprocessor and another is distributed memory multiprocessor. In shared memory multiprocessors, all the CPUs shares the common memory but in a distributed memory multiprocessor, every CPU has its own private memory.

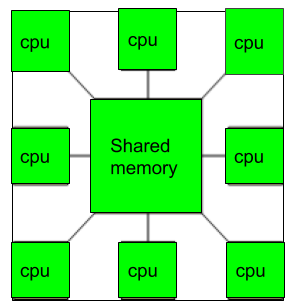
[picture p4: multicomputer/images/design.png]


_Applications of Multiprocessor_

* As a uniprocessor, such as single instruction, single data stream (SISD).
* As a multiprocessor, such as single instruction, multiple data stream (SIMD), which is usually used for vector processing.
* Multiple series of instructions in a single perspective, such as multiple instruction, single data stream (MISD), which is used for describing hyper-threading or pipelined processors.
* Inside a single system for executing multiple, individual series of instructions in multiple perspectives, such as multiple instruction, multiple data stream (MIMD).

_Benefits of using a Multiprocessor_

* Enhanced performance.
* Multiple applications.
* Multi-tasking inside an application.
* High throughput and responsiveness.
* Hardware sharing among CPUs.

_Advantages_

* Improved performance: Multiprocessor systems can execute tasks faster than single-processor systems, as the workload can be distributed across multiple processors.
* Better scalability: Multiprocessor systems can be scaled more easily than single-processor systems, as additional processors can be added to the system to handle increased workloads.
* Increased reliability: Multiprocessor systems can continue to operate even if one processor fails, as the remaining processors can continue to execute tasks.
* Reduced cost: Multiprocessor systems can be more cost-effective than building multiple single-processor systems to handle the same workload.
* Enhanced parallelism: Multiprocessor systems allow for greater parallelism, as different processors can execute different tasks simultaneously.

_Disadvantages_

* Increased complexity: Multiprocessor systems are more complex than single-processor systems, and they require additional hardware, software, and management resources.
* Higher power consumption: Multiprocessor systems require more power to operate than single-processor systems, which can increase the cost of operating and maintaining the system.
* Difficult programming: Developing software that can effectively utilize multiple processors can be challenging, and it requires specialized programming skills.
* Synchronization issues: Multiprocessor systems require synchronization between processors to ensure that tasks are executed correctly and efficiently, which can add complexity and overhead to the system.
* Limited performance gains: Not all applications can benefit from multiprocessor systems, and some applications may only see limited performance gains when running on a multiprocessor system.

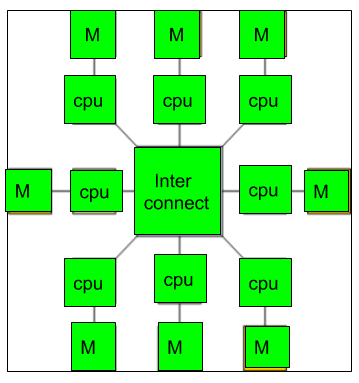
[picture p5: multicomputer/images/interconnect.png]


II. A multicomputer system is a computer system with multiple processors that are connected together to solve a problem. Each processor has its own memory and it is accessible by that particular processor and those processors can communicate with each other via an interconnection network.As the multicomputer is capable of messages passing between the processors, it is possible to divide the task between the processors to complete the task. Hence, a multicomputer can be used for distributed computing. It is cost effective and easier to build a multicomputer than a multiprocessor. Difference between multiprocessor and Multicomputer:

* Multiprocessor is a system with two or more central processing units (CPUs) that is capable of performing multiple tasks where as a multicomputer is a system with multiple processors that are attached via an interconnection network to perform a computation task.
* A multiprocessor system is a single computer that operates with multiple CPUs where as a multicomputer system is a cluster of computers that operate as a singular computer.
* Construction of multicomputer is easier and cost effective than a multiprocessor.
* In multiprocessor system, program tends to be easier where as in multicomputer system, program tends to be more difficult.
* Multiprocessor supports parallel computing, Multicomputer supports distributed computing.

_Advantages_

* Improved performance: Multicomputer systems can execute tasks faster than single-computer systems, as the workload can be distributed across multiple computers.
* Better scalability: Multicomputer systems can be scaled more easily than single-computer systems, as additional computers can be added to the system to handle increased workloads.
* Increased reliability: Multicomputer systems can continue to operate even if one computer fails, as the remaining computers can continue to execute tasks.
* Reduced cost: Multicomputer systems can be more cost-effective than building a single large computer system to handle the same workload.
* Enhanced parallelism: Multicomputer systems allow for greater parallelism, as different computers can execute different tasks simultaneously.

_Disadvantages_

* Increased complexity: Multicomputer systems are more complex than single-computer systems, and they require additional hardware, software, and management resources.
* Higher power consumption: Multicomputer systems require more power to operate than single-computer systems, which can increase the cost of operating and maintaining the system.
* Difficult programming: Developing software that can effectively utilize multiple computers can be challenging, and it requires specialized programming skills.
* Synchronization issues: Multicomputer systems require synchronization between computers to ensure that tasks are executed correctly and efficiently, which can add complexity and overhead to the system.
* Network latency: Multicomputer systems rely on a network to communicate between computers, and network latency can impact system performance

### Documents references

* Expired Patent [literature](https://patents.google.com/?inventor=Lawrence+S.+Mok)
* Multicomputing [DSP](https://www.semanticscholar.org/paper/A-multicomputer-type-DSP-system-for-super-signal-Ono-Kanayama/ee09a9bf444c2bd962d704a834e61a0ef8cb44b4)

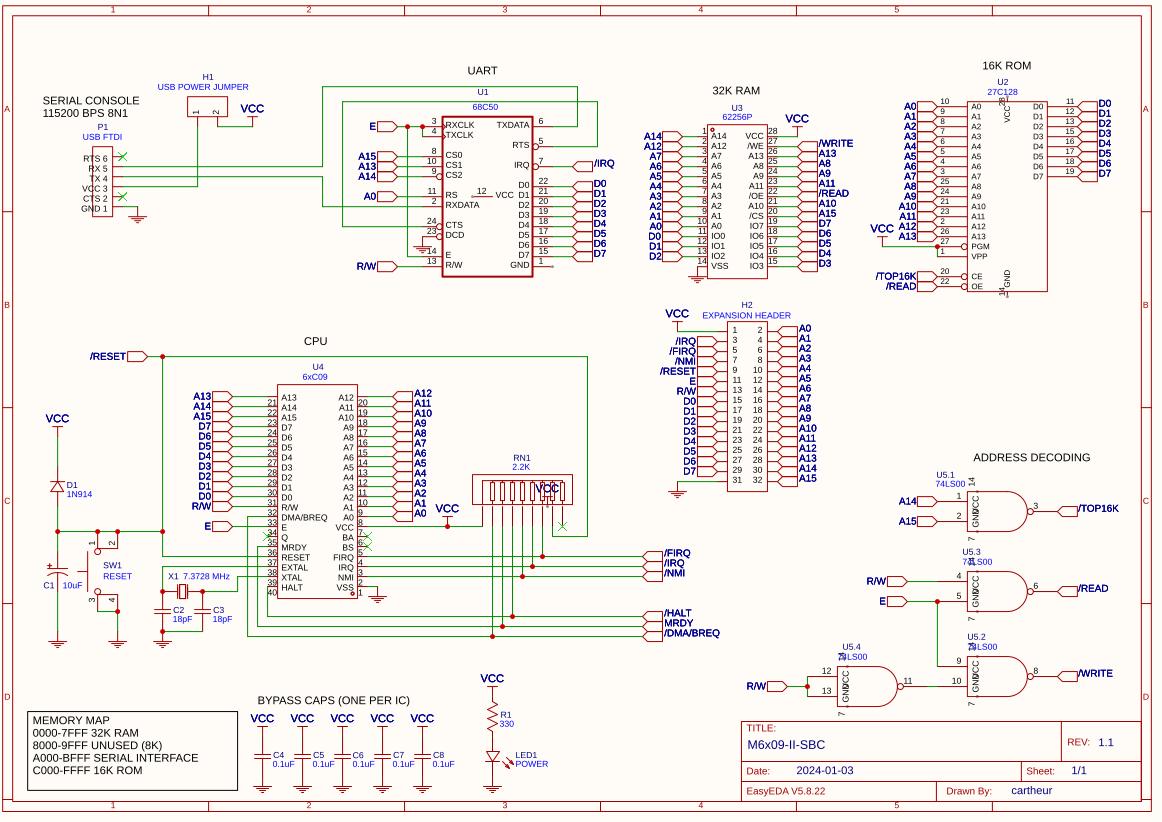
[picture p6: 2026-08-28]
build/project/schematic.jpg

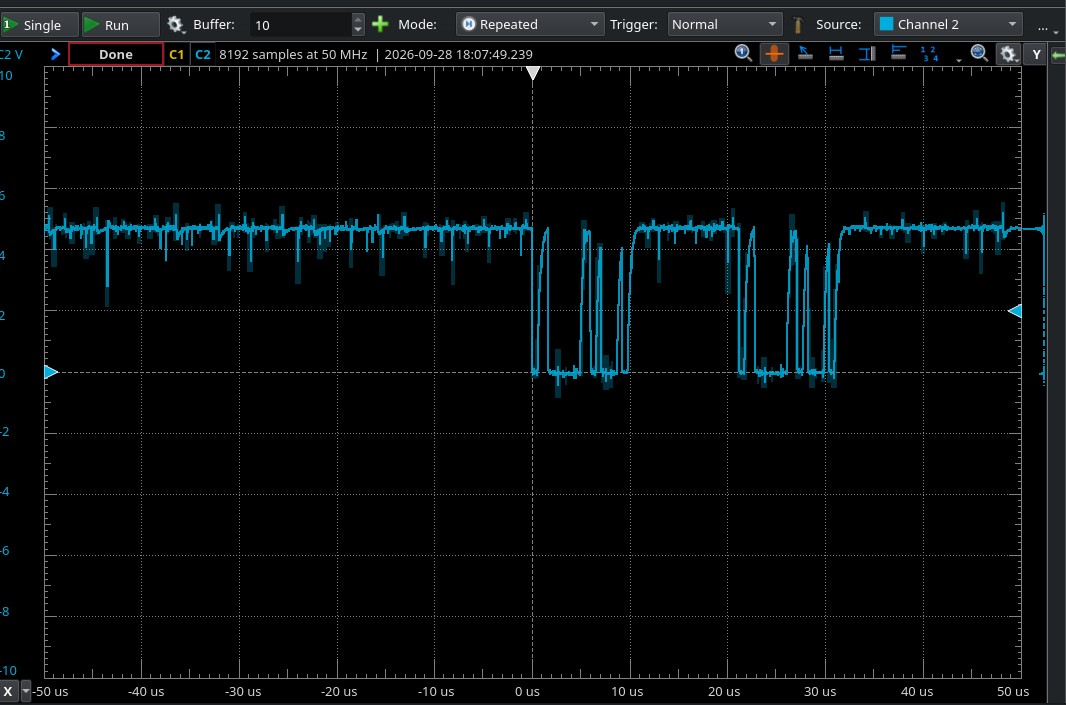
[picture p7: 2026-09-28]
images/acia-burst-narrow.jpg

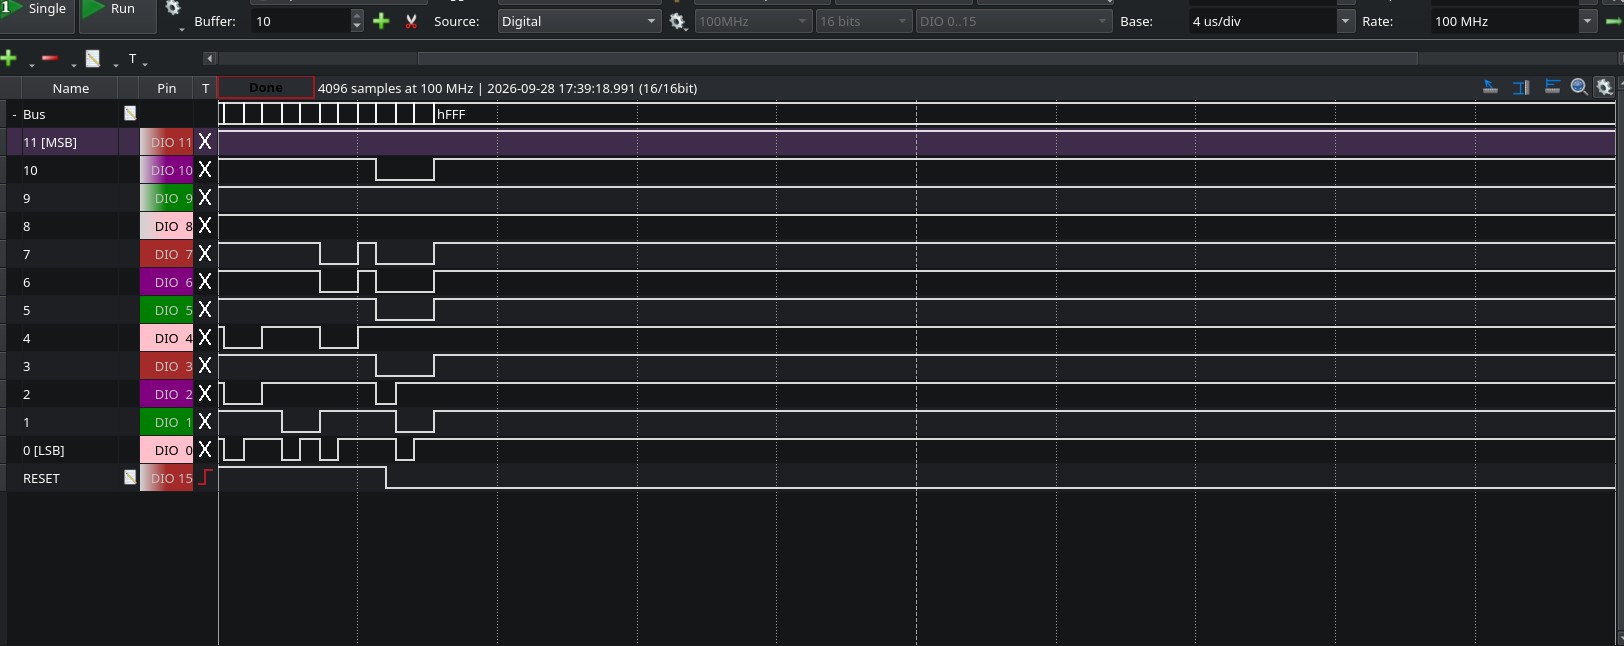
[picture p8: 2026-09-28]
images/RESET.jpg

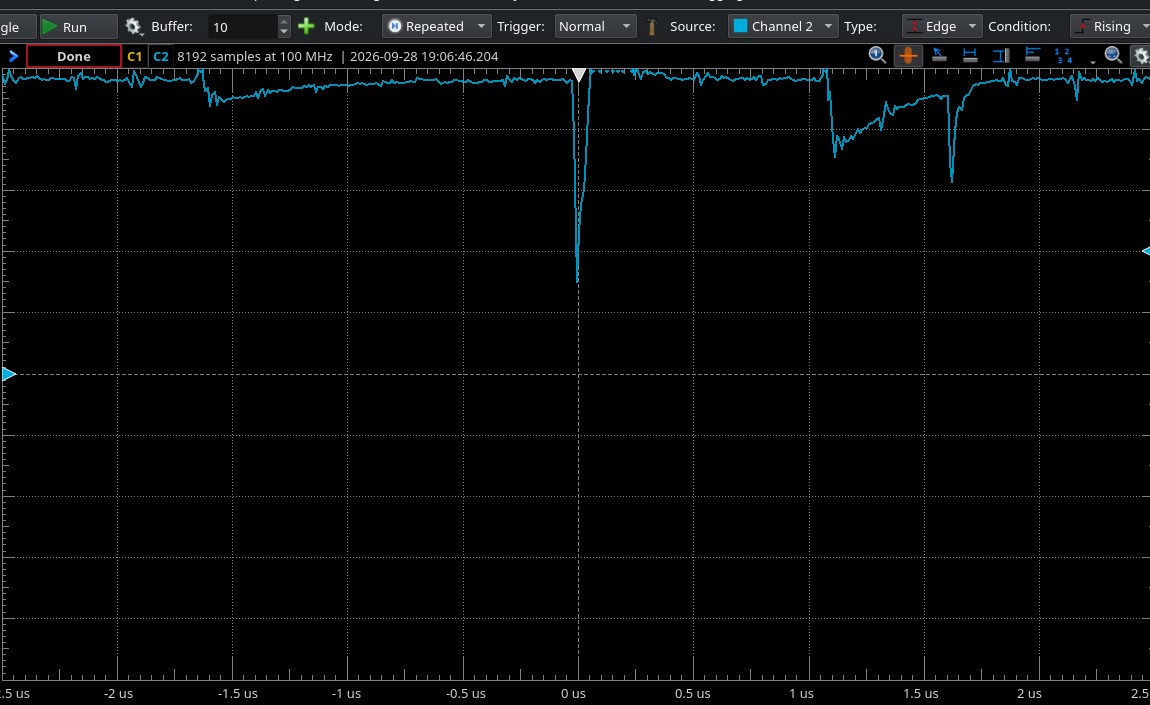
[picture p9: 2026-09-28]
images/nu-rom-reset.jpg

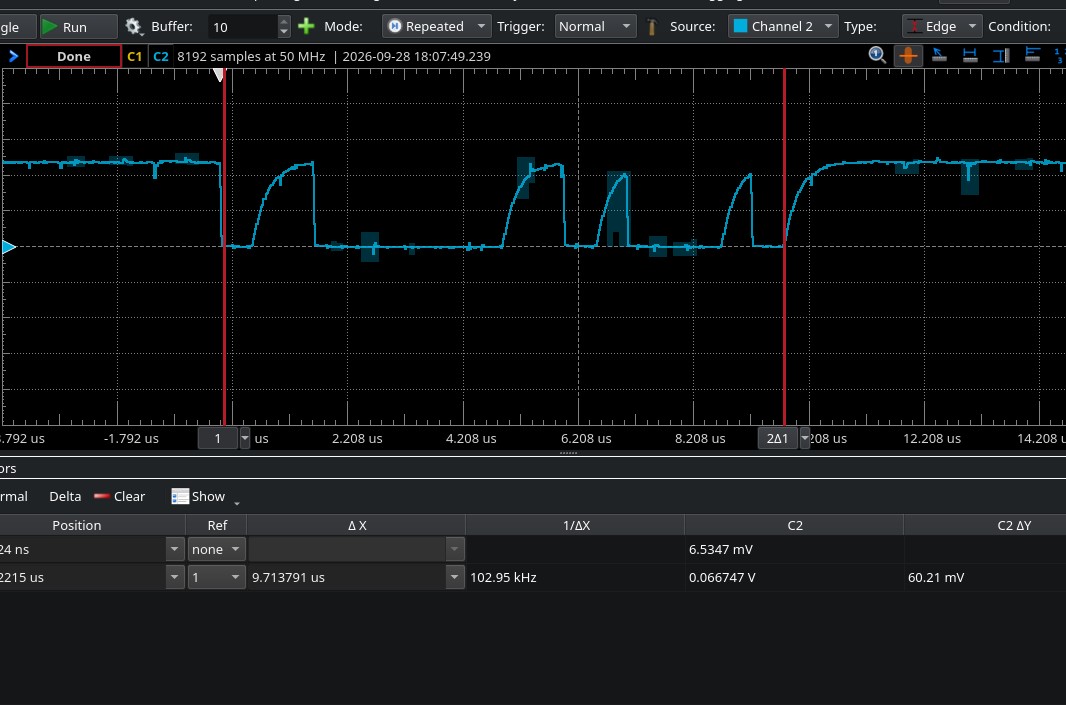
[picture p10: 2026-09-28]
images/acia-burst-cursors.jpg

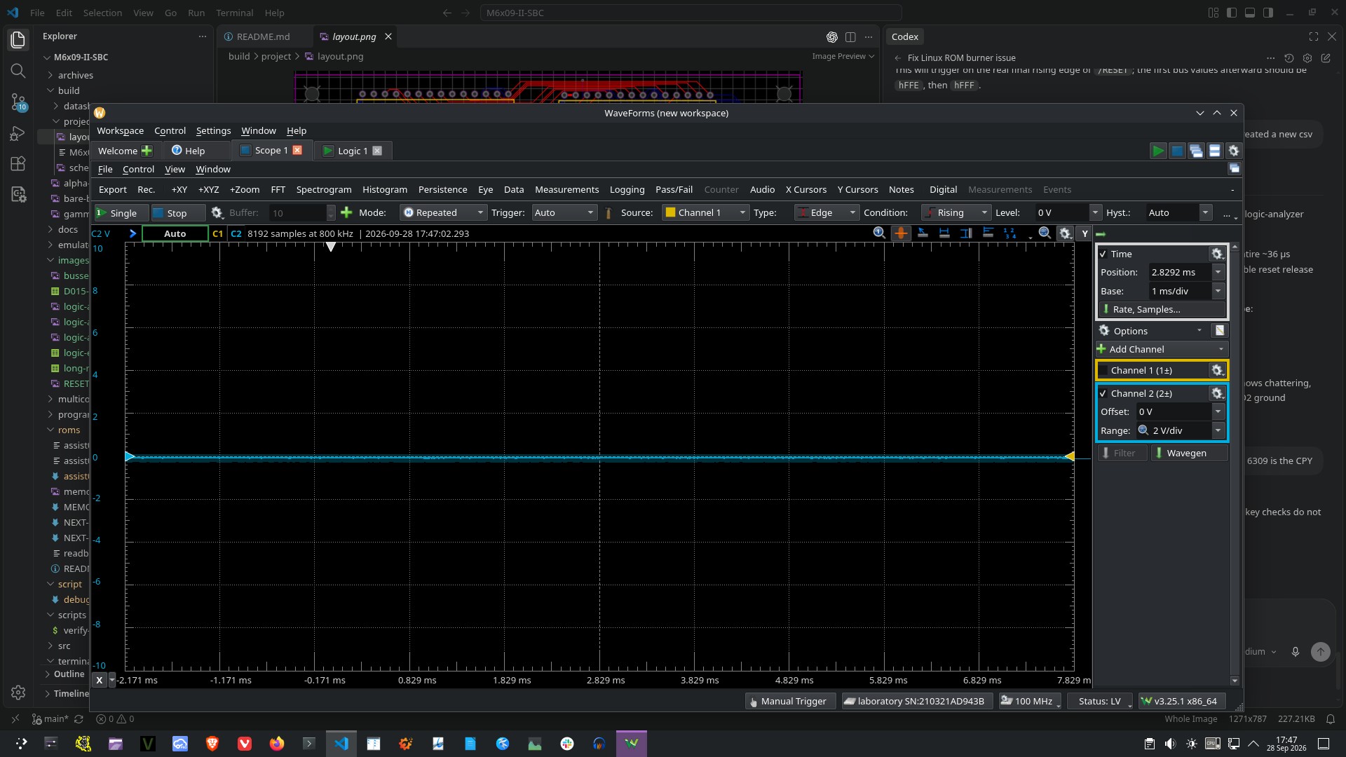
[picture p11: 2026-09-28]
images/reset-pressed.jpg

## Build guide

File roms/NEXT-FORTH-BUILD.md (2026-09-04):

# Next Build Step: Forth Port

Status: planned after ASSIST09 hardware acceptance.

The existing fig-Forth source is not a build candidate for the M6x09-II-SBC without a board-specific port. Its original target assumes RAM at `$C000-$DFFF`, ROM at `$E000-$FFFF`, and an ACIA at `$9800`; those assumptions conflict with the board [memory map](MEMORY-MAP.md).

## Entry Gate

Start this work only after the ASSIST09 milestone has recorded all of the following:

1. A verified Batronix program operation using [assist09-27c128.bin](assist09-27c128.bin).
2. An ASSIST09 boot banner and `>` prompt on the target board.
3. A successful `ASSIST09 RAM SMOKE TEST PASSED` result through the Tcl terminal.

## Port Process

1. Define the Forth RAM allocation inside the board's `$0000-$7FFF` RAM, excluding the ASSIST09 work page around `$5F00`.
2. Change the Forth ACIA constants from `$9800-$9801` to the board ACIA at `$BE00`.
3. Create a RAM-test build in which Forth code, dictionary, TIB, and stacks all occupy confirmed writable RAM.
4. Load that RAM-test S-record through ASSIST09 and prove terminal input, terminal output, dictionary writes, stack operations, and reset recovery.
5. Relocate the proven Forth ROM code into the available `$C000-$F7FF` ROM region while retaining ASSIST09 at `$F800-$FFFF` and its hardware vectors at `$FFF0-$FFFF`.
6. Build a full 16 KiB `27C128` programmer image with Forth in the lower ROM region and ASSIST09 in the final 2 KiB.
7. Program, verify, boot-test, and record the resulting ROM as a separate Forth milestone under `roms/`.

## Constraints

- Do not overwrite or relocate ASSIST09 until the Forth ROM has a separately proven reset and recovery path.
- Do not use the current Forth output as a programmer image; it targets incompatible memory and serial addresses.
- Do not choose a final Forth RAM range until the ASSIST09 work area and the required Forth dictionary and stack sizes have been measured.

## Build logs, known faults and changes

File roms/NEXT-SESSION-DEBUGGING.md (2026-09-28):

# Next Session: CTS And ACIA Transmit Enable

Date: 2026-09-28

Status: stop after the post-repair `RS`/`TXDATA` split capture. The repaired EPROM is programmed and fully read back; terminal acceptance is still pending. Do not change source before completing this session.

## Established Evidence

- `roms/readback.bin` is byte-for-byte identical to the corrected `roms/assist09-27c128.bin`: SHA-256 `37ece487da6b49c7d9f24deb34d25598983782a9ff958558f39a1dff2e5cc843`.
- Tcl opens `/dev/ttyUSB0` at `115200,n,8,1`, no handshake, but receives neither the ASSIST09 banner nor `>`.
- The CPU, reset release, E clock, ACIA Rx/Tx clocks, and address bus have already been observed active.
- Power-off continuity: H2 pin 2 (`A0`) to U1 pin 11 (`RS`) is present. U1 pin 11 has no continuity to U1 pin 12 (`VCC`).
- [same-acia.jpg](../images/same-acia.jpg): both AD2 scope channels connected to U1 pin 11 using a shared ground show the same active `RS` waveform. This validates the scope channel and ground arrangement.
- [split-acia.jpg](../images/split-acia.jpg): C1 on U1 pin 11 (`RS`) is active after reset; C2 on U1 pin 6 (`TXDATA`) remains idle high.

## Working Hypothesis

The corrected monitor polls ACIA status bit 1 (`TDRE`) before writing transmit data. On the MC6850/68C50, a high `CTS` input inhibits `TDRE`. If U1 pin 23 (`CTS`) is high, the observed active register-select traffic and idle TX output are expected.

This is a hypothesis, not a source-change authorization.

## Exact First Measurement

Make this connection with board power removed, then power the board through its normal FTDI connection:

| AD2 wire | Board connection |
| --- | --- |
| Scope C1+ | U1 pin 23 (`CTS`) |
| Scope C1- | board/FTDI GND |
| Scope C2+ (optional) | U1 pin 5 (`RTS`) |
| Scope C2- | same board/FTDI GND node |

Only one board GND pin is needed: join C1- and C2- at a shared ground node before connecting that node to board GND.

In WaveForms Scope, enable DC coupling and use 2 V/div. Select a 1 ms/div timebase and Repeated acquisition. Trigger Auto is sufficient because this is a DC-level measurement.

Record the measured CTS level after reset:

- **Near 0 V:** CTS is clear; continue by checking ACIA bus read/write and chip-select timing before considering source behavior.
- **Near 4.5 V:** CTS is blocking TDRE and is the immediate cause of the idle TX line. Trace the CTS connection to the FTDI/control wiring and decide the hardware remedy before touching firmware.

## Session Boundary

Preserve the CTS capture and its measured voltage. Do not erase, reprogram, or replace the verified EPROM, and do not make a new source commit during this measurement session. The next decision follows the observed CTS level.

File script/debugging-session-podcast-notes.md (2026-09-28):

# M6x09-II-SBC Debugging Session Notes

Use this document as the live technical log and narrative outline for the future podcast episode. Record an observation before interpreting it, retain terminal and scope captures, and distinguish confirmed facts from hypotheses.

## Starting State

- The FTDI adapter and host terminal passed a TX-to-RX loopback test at `19200,n,8,1`, no handshake.
- The board power LED lights, but the SBC has not produced an ASSIST09 banner or `>` prompt.
- The pre-correction `roms/assist09-27c128.bin` image was 16 KiB and carried ASSIST09 at `$F800-$FFFF` with reset vector `$F837`, but it had not passed board acceptance.
- The checked-in assembler executable is a 32-bit 2004 binary which fails on this host with `Bad system call`. The repository now builds an ignored native `as9-host` executable from the original source with GNU89 mode, leaving the historical binary intact.

## Confirmed Software Faults

The ASSIST09 ACIA polling code is not consistent with the checked-in MC6850 data sheet:

- `CIDTA` at `src/assist-09/assist09.asm` reads ACIA status and shifts it twice. Its carry test therefore observes status bit 1 (`TDRE`, transmit-data-register empty), while the comment says it is testing receive data.
- `CODTAO` tests status bit 0 (`RDRF`, receive-data-register full) while its comment says it is waiting for transmit readiness. The source itself marks this `FIXME`.
- The schematic connects CPU `A0` directly to the 6850 `RS` input. Therefore `$BE00` is the data register and `$BE01` is control/status. `COON` reads status at `$BE01` elsewhere in the source, but writes its `$03` reset and `$51` control bytes to `$BE00`; those bytes are transmitted as data rather than configuring the ACIA.

These errors can prevent reliable console input and output even when the board is electrically healthy. Commit `da931d9` corrects them: `COON` writes to `1,X`; `CIDTA` tests `RDRF`; and `CODTAO` tests `TDRE` and waits only while it is clear. The corrected image still requires EPROM programming and hardware acceptance before this becomes a board-level conclusion.

## High-Value Serial Hypothesis

The schematic connects the ACIA `RxC` and `TxC` pins to the 6809 `E` clock. With the documented 7.3728 MHz oscillator, `E` is expected to be 1.8432 MHz. The corrected ASSIST09 candidate initializes the ACIA with `$51`; its low control bits select the MC6850 divide-by-16 mode. If those schematic connections and clock assumptions are correct, the resulting serial rate is **115200 baud**, not the repository's historical 19200 baud setting.

Test `115200,n,8,1`, no handshake, before changing board wiring. Confirm the clock frequencies with a scope before declaring this conclusion final.

## Session Order

1. Photograph chip markings, orientation, FTDI wiring, jumper H1 state, and the EPROM programmer's selected device and verification result.
2. Save a terminal recording and test the board at 115200 with no handshake. Retain a separate capture for the existing 19200 setting.
3. With power removed, continuity-check FTDI `TXO -> U1 pin 2`, FTDI `RXI -> U1 pin 6`, and common ground. Confirm no unintended dual power source.
4. Measure VCC at the CPU, ROM, RAM, and ACIA. Then observe reset release, the 7.3728 MHz oscillator, CPU `E`, and ACIA `RxC`/`TxC`.
5. Confirm that reset fetches `$FFFE-$FFFF`, resolves to `$F837`, and that the CPU subsequently reads ROM instructions.
6. Probe ACIA TX: it should idle high and transition during monitor output. Correlate this capture with the terminal log.
7. After a stable ASSIST09 `>` prompt, load `src/assist-09/assist09-smoke.s19`, run `G 1000`, and preserve the complete `ASSIST09 RAM SMOKE TEST PASSED` output.

## Podcast Evidence Checklist

For each test, record the date, board revision, CPU/ACIA/EPROM markings, power source, EPROM image SHA-256, terminal configuration, instrument settings, raw observation, and conclusion. Keep photos and captures immutable; place interpretation and follow-up actions in the session log.

## Emulator Evidence: Reset And ACIA Slice

The native C emulator loads the 16 KiB image, reads the reset vector as `$F8,$37`, and executes ASSIST09's vector-initialization routine through its return to `$F83D`. The CPU implementation is intentionally partial: unsupported instructions stop explicitly instead of generating a plausible but false result.

The pre-correction ROM reproduced three failures in executable form: `$03` and `$51` went to `$BE00` (data), leaving `$BE01` control untouched; receive polling observed `TDRE`; and `CODTAO` made its transmit decision from `RDRF`. The corrected-ROM regression test now verifies that `$51` reaches `$BE01`, an output byte is sent when `TDRE` is set, and the routine waits when `TDRE` is clear. This supports the source-level diagnosis, but it does not replace a physical ACIA or scope observation.

## Build-Contract Evidence

Rebuilding with `as9-host` exposed an important artifact-layout constraint. Removing the obsolete second `LSRA` instruction initially made the raw monitor 2,047 bytes. The 16 KiB image target then failed its size guard: 14,336 bytes of `0xFF` padding plus 2,047 bytes of monitor made a 16,383-byte EPROM image. The assembler does not automatically fill the gap created before its fixed-vector `ORG`, so the image could have been malformed even though the source assembled.

The correction preserves the removed instruction's byte with a `NOP`. The rebuilt monitor is again exactly 2,048 bytes; its reset vector remains `$F837`; the full programmer image is exactly 16 KiB; and its checksum verifies. This is a host-side acceptance result, not evidence that the EPROM or board works.

## Corrected Candidate Identity

- Source and image milestone: commit `da931d9` (`Fix ASSIST09 ACIA initialization and polling`)
- Raw monitor: `src/assist-09/assist09.bin`, 2,048 bytes, SHA-256 `6175249f8ea71f8bc4e3c0e92745f4b1a9f8941e078106bf9b196dff904f7592`
- Programmer image: `roms/assist09-27c128.bin`, 16,384 bytes, SHA-256 `1d7fdbe412c8e57084b99b981a24c8fbdbc013227a6da04b1810c67054aa2d72`
- Host checks passed: `scripts/verify-assist09-image.sh`, `make -C emulator test`, and `sha256sum -c assist09-27c128.bin.sha256` from `roms/`.

## Programmer And First-Boot Evidence (2026-09-28)

The corrected 16 KiB image was programmed from the Windows host. Its complete EPROM readback was preserved as `roms/readback.bin` and compared on Linux with `roms/assist09-27c128.bin`: all 16,384 bytes matched, with the expected SHA-256 `1d7fdbe412c8e57084b99b981a24c8fbdbc013227a6da04b1810c67054aa2d72`. This confirms the programmed device contents, not board execution.

The first boot remained silent. At `115200,n,8,1`, no handshake, resetting the board produced neither the `ASSIST09` banner nor a `>` prompt. A separate direct 45-second FTDI capture sent a carriage return and included a board reset; it received zero bytes. The terminal GUI is therefore not the immediate explanation. The physical acceptance work now begins with reset release, CPU clock, and reset-vector fetch at `$FFFE-$FFFF` (expected vector `$F837`), before moving to ACIA TX and serial wiring.

## Reset, Clock, And Address-Bus Milestone (2026-09-28)

The next physical observations narrowed the silence without changing firmware. The AD2 scope showed the board's reset circuit behaving as an RC release: holding Reset drove H2 pin 7 low, and releasing it produced a smooth rise that settled near 4.5 V after roughly 100–150 ms. A short digital capture had misleadingly appeared to show reset chatter; it was sampling the slow analog ramp as it crossed the analyzer threshold. The long capture made the distinction visible.

With reset released, H2 pin 9 (`E`) measured 1.8431 MHz, exactly the expected CPU E-clock rate derived from the 7.3728 MHz oscillator. The AD2 Logic Analyzer then captured continuously changing values on H2 A0–A11, grouped as a hexadecimal bus. The CPU is therefore receiving power, leaving reset, clocking, and generating address-bus activity. The HD6309 installed in the board remains compatible with the ASSIST09/6809 reset-vector and bus assumptions used here.

The diagnostic sequence was deliberately incremental: correct the FTDI supply jumper, scope reset over a long enough interval to see its RC release, verify E-clock, then observe the lower address bus. Each step removed one category of failure without claiming serial success. The next instrument point is ACIA TX—U1 pin 6 / P1 pin 5—after the reset-release delay. It should idle high and show 115200-baud traffic during the ASSIST09 banner. A continued idle line would move the investigation to the ACIA's supply, select/control signals, and TX routing rather than the terminal application.

## The ACIA Turn: When the Firmware Met the Pinout

The TX probe did not remain idle. U1 pin 6 showed real digital bursts, while U1 pins 3 and 4 showed the expected receive and transmit clocks at approximately 1.843 MHz. That result moved the question from “is the ACIA alive?” to “what configuration did it receive?” The `RS` probe supplied the final bridge between firmware and hardware.

The MC6850 defines `RS=0` for Control/Status and `RS=1` for Transmit/Receive Data. The board routes CPU A0 directly to U1 pin 11 (`RS`), making `$BE00` Control/Status and `$BE01` Data. The monitor had those two offsets reversed. Its apparent ACIA initialization wrote `$03` and `$51` to the data register; the short TX bursts were the ACIA transmitting those values at its default divide-by-1 rate rather than accepting a 115200-baud configuration.

This is the point where disciplined measurement earned a source change. The repair is intentionally small and mechanical: offset 0 for status/control and offset 1 for data in `CIDTA`, `COON`, and `CODTAO`. The emulator model and regression test were corrected to the same map. The resulting 2,048-byte monitor and 16 KiB programmer image pass the emulator, clean-room image verifier, and checksum check; the new programmer-image SHA-256 is `37ece487da6b49c7d9f24deb34d25598983782a9ff958558f39a1dff2e5cc843`. The corrected EPROM was then programmed and its complete 16,384-byte readback matched that checksum byte for byte. Board boot remains the next hardware result.

The first post-repair capture did not earn a second source change. With a shared scope ground, both channels on U1 pin 11 agreed that `RS` was active; continuity also verified H2 `A0` to that pin. But the split capture, `RS` versus U1 pin 6 (`TXDATA`), showed an addressed ACIA with its TX output idle. That observation moves the next question to U1 pin 23 (`CTS`): a high CTS suppresses `TDRE`, so the monitor can correctly poll forever without sending a character. The session stops there, with CTS measurement—not another firmware edit—the next controlled step.

## A Note On Agents And Responsibility

This debugging session is also part of the episode's argument against treating an agent's output as self-authenticating. An agent, operating through the project account, made an honest but consequential ACIA mapping mistake while attempting to fix the monitor. The inherited archive code already contained part of the reversal; the later agent change extended it to initialization. Neither intent nor passing host tests was enough to make the result correct.

The developer's responsibility does not disappear when an agent writes code: review the proposed change, compare it with the authoritative data sheet and schematic, measure the hardware, and retain evidence. Here the ROM readback, reset waveform, clocks, TX waveform, and `RS` trace turned an apparently plausible software fix into a falsifiable hardware claim. That is the standard the episode should leave with subscribers: use agents as collaborators, but keep diagnosis and acceptance accountable to the developer.

## Two EPROMs, Not an Expanding Pile

For greenfield development, keep two erasable EPROMs in a deliberate burn rotation. Each receives a named, host-verified candidate, with its image checksum and a complete readback recorded. After those two development versions have served their diagnostic purpose, erase and reuse one for the next candidate rather than reaching for a third or fourth chip.

Agents can make mistakes, and a disciplined hardware diagnosis can require more than two burn sessions—as this board's history demonstrates. That is an argument for a tight two-chip cycle, not for accumulating a pile of indistinguishable EPROMs. Reuse keeps the work focused on the current debugging hypothesis and its final result, while the repository preserves the evidence for every meaningful burn.

## Active Working Step: First-Boot Hardware Diagnosis

This is the current hand-off from host/emulator work to physical hardware.

This step is the technical core of the titular podcast Episode 13, **“Feel the (ROM) burn.”** The episode follows the corrected image from reproducible host artifact, through independently verified programming and physical installation, to the next disciplined hardware observation.

1. Apply the ACIA register-offset source repair, then rebuild and host-verify a new 16 KiB programmer image.
2. Program and full-device-readback verify that new image before installing it.
3. Probe TX again; the frame timing should now be 115200 baud (about 8.68 us per bit) rather than the default divide-by-1 timing.
4. Once serial output appears, capture the `ASSIST09` banner and `>` prompt at `115200,n,8,1`, no handshake. Only then build and send `src/assist-09/assist09-smoke.s19`, run `G 1000`, and record `ASSIST09 RAM SMOKE TEST PASSED`.

Capture the backup filename and checksum, programmer device selection and verify result, EPROM orientation, terminal configuration, and every observed character. A silent first boot is still useful evidence: proceed to the board-side voltage, reset, clock, reset-vector, and ACIA-TX checks rather than changing multiple variables at once.

## Why The Emulator Was Worth The Investment

The board began as a silent physical object. A scope-first session could have consumed hours validating power, reset, clocks, wiring, and levels without revealing that the firmware addressed the ACIA inconsistently. The emulator made the hardware contract executable: memory placement, reset-vector fetch, `A0 -> RS`, ACIA status bits, and data/control register behavior were all stated as testable rules.

That investment also guarded the build chain. The 2,047-byte regression was caught by the programmer-image size check before a chip was programmed, while the emulator regression confirmed that the replacement `NOP` preserved execution through the reset path. The result is not merely a more convenient debugger; it is a way to prevent an incorrect artifact from becoming a misleading hardware symptom.

## Narrative Arc

The episode can trace the difference between reproducible bytes and a working machine: a legacy toolchain made reproducible again; a one-byte layout regression caught before programming; an emulator that turned a silent-board mystery into three precise ACIA defects; and a corrected image that must still earn its claim on real hardware. The through-line is that an emulator does not replace instruments—it makes their time more valuable by narrowing exactly what the physical session must prove.

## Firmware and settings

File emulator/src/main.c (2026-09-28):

#include "cpu6809.h"

#include <stdio.h>
#include <string.h>

static void usage(const char *program)
{
    fprintf(stderr, "Usage: %s --rom PATH\n", program);
}

int main(int argc, char **argv)
{
    M6x09Machine machine;
    M6x09Cpu6809 cpu;
    const char *rom_path = NULL;

    if (argc == 3 && strcmp(argv[1], "--rom") == 0) {
        rom_path = argv[2];
    } else {
        usage(argv[0]);
        return 2;
    }

    m6x09_machine_init(&machine);
    if (!m6x09_load_rom(&machine, rom_path)) {
        fprintf(stderr, "Unable to load a 16 KiB ROM image: %s\n", rom_path);
        return 1;
    }

    m6x09_reset(&machine);
    m6x09_cpu6809_reset(&cpu, &machine);
    printf("ROM loaded: %s (16 KiB)\n", rom_path);
    printf("reset reads: $FFFE=$%02X $FFFF=$%02X\n",
           m6x09_read(&machine, M6X09_RESET_VECTOR),
           m6x09_read(&machine, M6X09_RESET_VECTOR + 1));
    printf("reset PC: $%04X\n", machine.program_counter);
    printf("ACIA status: $%02X (TDRE=%u RDRF=%u)\n", machine.acia.status,
           (machine.acia.status & M6X09_ACIA_TDRE) != 0,
           (machine.acia.status & M6X09_ACIA_RDRF) != 0);
    printf("first opcode: $%02X at $%04X\n", m6x09_read(&machine, cpu.pc), cpu.pc);
    printf("CPU reset-path instruction subset is available; monitor SWI is not implemented yet.\n");
    return 0;
}

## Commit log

2023-12-30 Add BoM
    [BOM_M6x09-II-SBC.csv]
2023-12-30 Add schematic snap
2023-12-30 Add Gerber collection
    [Drill_NPTH_Through.DRL, Drill_PTH_Through.DRL, Drill_PTH_Through_Via.DRL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]
2023-12-30 Posit as design
    [BOM_M6x09-II-SBC.csv]
2023-12-30 Place board on main
2023-12-30 Add 610P device list
2023-12-30 Add CAD models
2024-01-01 Complete BoM
    [BOM_M6x09-II-SBC.csv]
2024-01-03 Update schematic
2024-01-03 Add BoM as table
2024-01-03 Add v1.1 Gerber files
    [Drill_NPTH_Through.DRL, Drill_PTH_Through.DRL, Drill_PTH_Through_Via.DRL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]
2024-01-03 Add code-assembler section
2024-01-04 Corrected part number
    [BOM_M6x09-II-SBC.csv]
2024-01-14 Add updated files
    [Drill_NPTH_Through.DRL, Drill_PTH_Through.DRL, Drill_PTH_Through_Via.DRL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]
2026-08-18 Add real board image
2026-08-19 Sample free
2026-09-04 Align toward board build
2026-09-04 Align board build
    [BOM_M6x09-II-SBC.csv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]
2026-09-28 Emulate ASSIST09 reset vector initialization
    [main.c]
2026-09-28 Document ROM and reset diagnostics
    [D015-rise.csv, logic-export.csv, long-reset.csv]
